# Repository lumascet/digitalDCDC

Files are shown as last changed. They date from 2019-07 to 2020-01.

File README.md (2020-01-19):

# Atmel atmega 328p DCDC controller
Arduino Uno Project for digitally controlling DCDC converter with adc & dac over i2c with dotmatrix display.
Utilizes the cheap B3606 analog DCDC converter circuit.

The onboard 4.096V reference in combination with 2 12bit DACs as well as one 4 Channel 16bit ADC enable accurate voltage and current setpoints. 

The graphical interface also features a graph display, showing voltage and current over time.

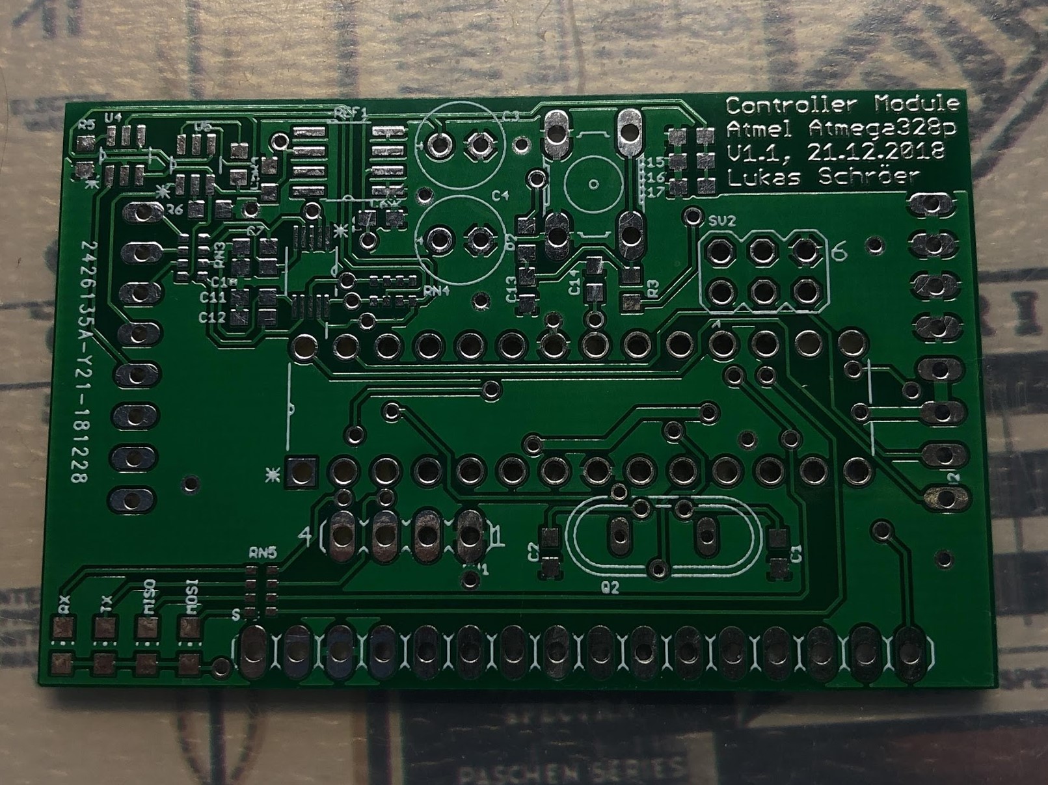
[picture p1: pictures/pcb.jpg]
pcb

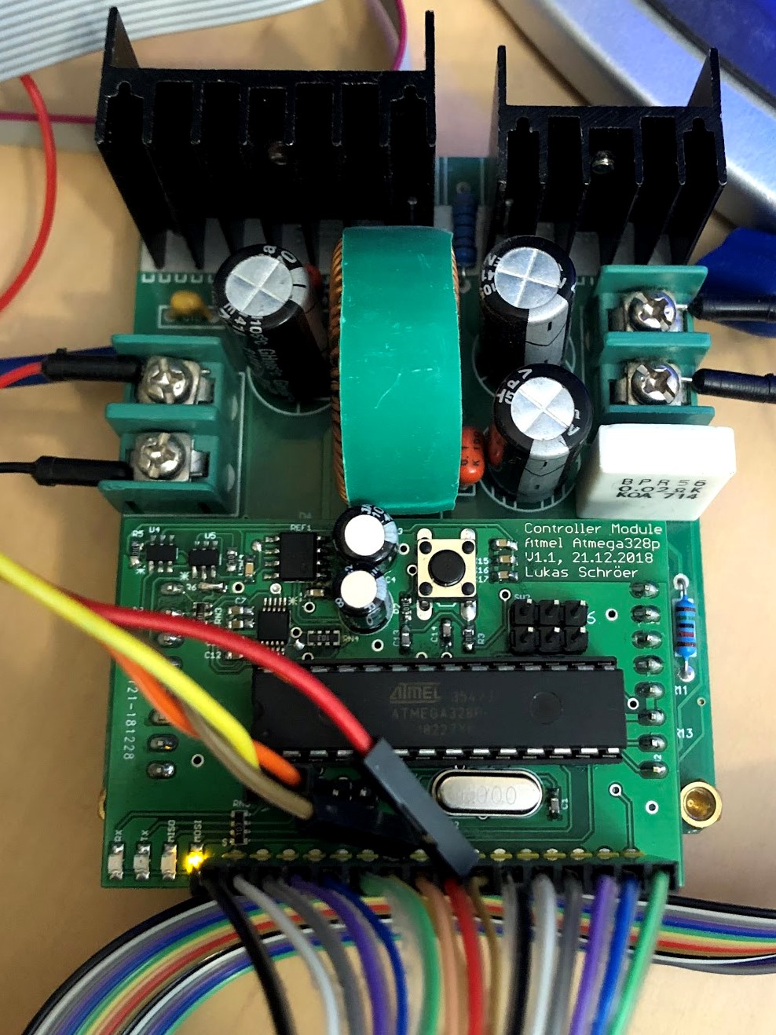
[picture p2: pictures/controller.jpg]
controller

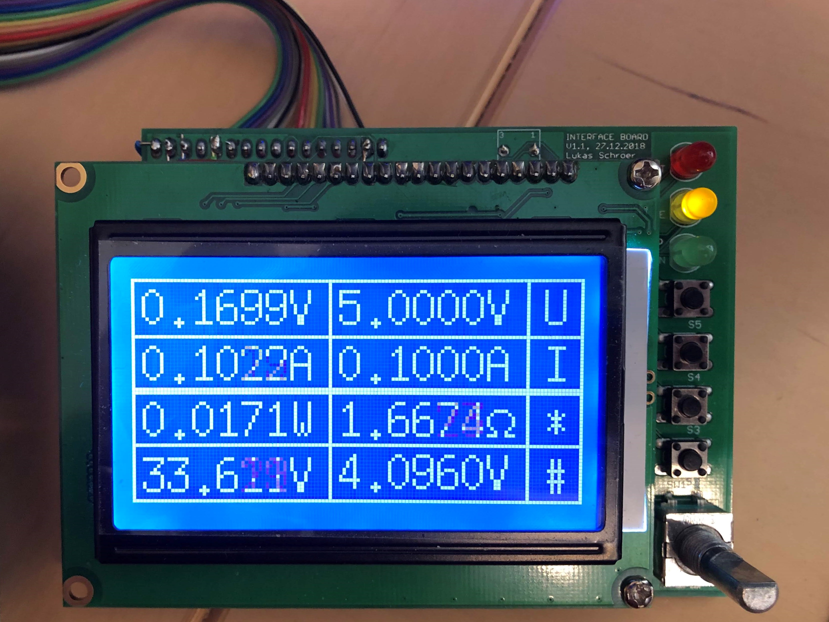
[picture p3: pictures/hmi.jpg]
hmi


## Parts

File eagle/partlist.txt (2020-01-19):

Partlist

Exported from ControllerRC2.brd at 25.02.2019 17:07

EAGLE Version 9.2.2 Copyright (c) 1988-2018 Autodesk, Inc.

Assembly variant: 

Part     Value           Package            Library                                Position (inch)       Orientation

C1       22p             C0603              rcl                                    (2.6 2.0625)          R270
C2       22p             C0603              rcl                                    (2.075 2.0625)        R270
C3       10µ             E2,5-6E            rcl                                    (1.8625 3.05)         R0
C4       10µ             E2,5-6E            rcl                                    (1.8625 2.8125)       R0
C5       1n              C0603              rcl                                    (1.39375 2.96875)     R90
C6       100n            C0603              rcl                                    (1.66875 2.86875)     R0
C7       1µ              C0603              rcl                                    (1.3625 2.8)          R180
C8       330n            C0603              rcl                                    (1.2875 1.890625)     MR90
C9       100n            C0603              rcl                                    (1.2875 2.0125)       MR90
C10      1µ              C0603              rcl                                    (1.3625 2.75)         R180
C11      1µ              C0603              rcl                                    (1.3625 2.675)        R180
C12      1µ              C0603              rcl                                    (1.3625 2.625)        R180
C13      22p             C0603              rcl                                    (2.025 2.6875)        R270
C14      22p             C0603              rcl                                    (2.1875 2.7125)       R90
C15      100n            C0603              rcl                                    (2.425 3.0625)        R180
C16      100n            C0603              rcl                                    (2.425 3)             R180
C17      100n            C0603              rcl                                    (2.425 2.9375)        R180
IC1      MCP602SN        SO08               linear                                 (1.3 2.675)           MR0
IC4      REG1117-3.3     SOT223             burr-brown                             (1.0875 1.95)         MR270
MISO     YELLOW          CHIP-LED0805       led                                    (1.1375 1.85)         R0
MOSI     YELLOW          CHIP-LED0805       led                                    (1.2375 1.85)         R0
Q2       16M             QS                 special                                (2.3375 2.1)          R180
R1       10k             R0603              rcl                                    (1.375 2.475)         MR180
R2       10k             R0603              rcl                                    (2.025 2.8125)        R90
R3       10k             R0603              rcl                                    (2.275 2.6875)        R270
R4       10k             R0603              rcl                                    (1.31875 3.00625)     R270
R5       10k             R0603              rcl                                    (0.9375 3.03125)      R270
R6       0               R0603              rcl                                    (1.25 2.89375)        R180
R7       10k             R0603              rcl                                    (2.1375 2.35)         MR180
R8       33k             R0603              rcl                                    (1.7875 2.3625)       MR270
R9       33k             R0603              rcl                                    (1.9375 2.3625)       MR270
R10      10k             R0603              rcl                                    (2.1375 2.4125)       MR180
R11      6.8k            R0603              rcl                                    (1.25 2.475)          MR180
REF1     ISL21009BFB841Z SOIC127P600X175-8N custom                                 (1.5875 3.0125)       R180
RN3      10k             0603-ARC           resistor-dil                           (1.2125 2.775)        R270
RN4      10k             0603-ARC           resistor-dil                           (1.7 2.6875)          R0
RN5      1k              0603-ARC           resistor-dil                           (1.4 1.975)           R90
RX       YELLOW          CHIP-LED0805       led                                    (0.9375 1.85)         R0
S1                       B3F-10XX           switch-omron                           (2.1875 2.946875)     R90
SV1                      MA04-1             con-lstb                               (1.7375 2.1)          R180
SV2                      MA03-2             con-lstb                               (2.5875 2.725)        R0
SV3                      1X16               pinhead                                (2.1375 1.8375)       R0
TX       YELLOW          CHIP-LED0805       led                                    (1.0375 1.85)         R0
U$1      DCPINHEADER     CDIP16             custom                                 (2.0875 2.5875)       R0
U1       ADS1115IDGST    SOP50P490X110-10N  Texas Instruments_By_element14_Batch_1 (1.5 2.7375)          R270
U2       ATMEGA328P-PU   DIP254P762X457-28  Atmel_By_element14_Batch_1-00          (2.7875 2.55)         R90
U4       MCP4725A0T-E/CH SOT95P270X145-6N   Microchip_By_element14_Batch_1         (1.0375 3.03125)      R90
U5       MCP4725A0T-E/CH SOT95P270X145-6N   Microchip_By_element14_Batch_1         (1.2125 3.00625)      R90

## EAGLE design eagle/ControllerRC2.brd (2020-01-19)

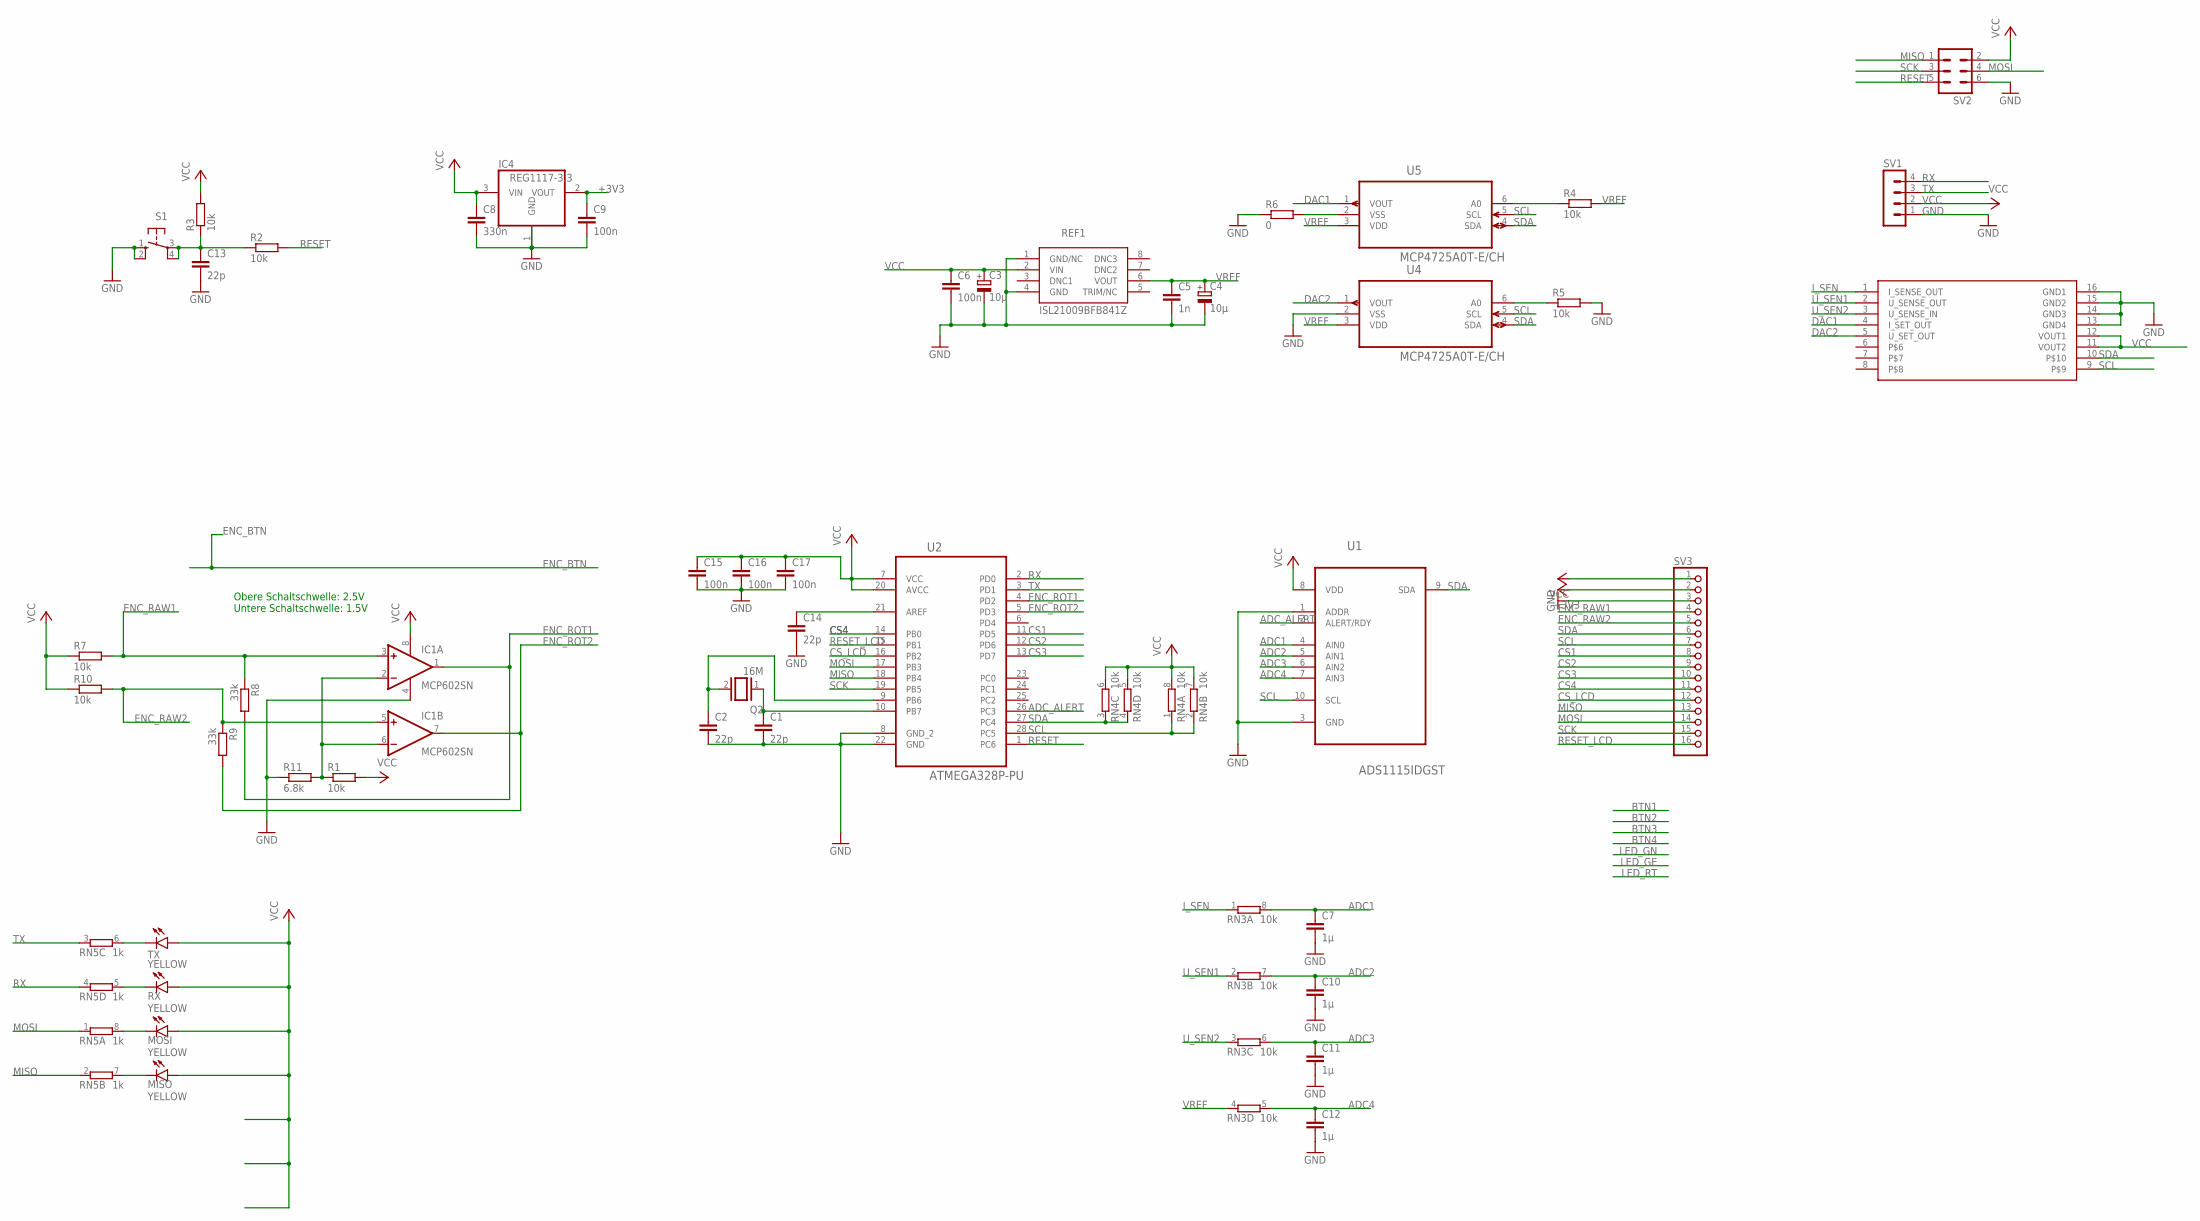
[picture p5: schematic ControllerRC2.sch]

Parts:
C1, C2, C13, C14: 22p; C0603
C3, C4: 10µ; E2,5-6E
C5: 1n; C0603
C6, C9, C15, C16, C17: 100n; C0603
C7, C10, C11, C12: 1µ; C0603
C8: 330n; C0603
IC1: MCP602SN; SO08
IC4: REG1117-3.3; SOT223
MISO: YELLOW; CHIP-LED0805
MOSI: YELLOW; CHIP-LED0805
Q2: 16M; QS
R1, R2, R3, R4, R5, R7, R10: 10k; R0603
R6: 0; R0603
R8, R9: 33k; R0603
R11: 6.8k; R0603
REF1: ISL21009BFB841Z; SOIC127P600X175-8N
RN3, RN4: 10k; 0603-ARC
RN5: 1k; 0603-ARC
RX: YELLOW; CHIP-LED0805
S1: 10-XX; B3F-10XX
SV1: MA04-1
SV2: MA03-2
SV3: PINHD-1X16; 1X16
TX: YELLOW; CHIP-LED0805
U1: ADS1115IDGST; SOP50P490X110-10N
U2: ATMEGA328P-PU; DIP254P762X457-28
U4, U5: MCP4725A0T-E/CH; SOT95P270X145-6N
U$1: DCPINHEADER; CDIP16

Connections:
+3V3: C9.1, IC4.2 (VOUT), SV3.2
ADC1: C7.1, RN3.8 (2), U1.4 (AIN0)
ADC2: C10.1, RN3.7 (2), U1.5 (AIN1)
ADC3: C11.1, RN3.6 (2), U1.6 (AIN2)
ADC4: C12.1, RN3.5 (2), U1.7 (AIN3)
ADC_ALERT: U1.2 (ALERT/RDY), U2.26 (PC3)
CS1: SV3.8, U2.11 (PD5)
CS2: SV3.9, U2.12 (PD6)
CS3: SV3.10, U2.13 (PD7)
CS4: SV3.11, U2.14 (PB0)
CS_LCD: SV3.12, U2.16 (PB2)
DAC1: U5.1 (VOUT), U$1.4 (I_SET_OUT)
DAC2: U4.1 (VOUT), U$1.5 (U_SET_OUT)
ENC_RAW1: IC1.3 (+IN), R7.2, R8.1, SV3.4
ENC_RAW2: IC1.5 (+IN), R9.1, R10.2, SV3.5
ENC_ROT1: IC1.1 (OUT), R8.2, U2.4 (PD2)
ENC_ROT2: IC1.7 (OUT), R9.2, U2.5 (PD3)
GND: C1.2, C2.2, C3.-, C4.-, C5.2, C6.2, C7.2, C8.2, C9.2, C10.2, C11.2, C12.2, C13.2, C14.2, C15.2, C16.2, C17.2, IC1.4 (V-), IC4.1 (GND), R5.2, R6.1, R11.1, REF1.1 (GND/NC), REF1.4 (GND), S1.1 (S), S1.2 (S1), SV1.1, SV2.6, SV3.3, U1.1 (ADDR), U1.3 (GND), U2.8 (GND_2), U2.22 (GND), U4.2 (VSS), U$1.13 (GND4), U$1.14 (GND3), U$1.15 (GND2), U$1.16 (GND1)
I_SEN: RN3.1, U$1.1 (I_SENSE_OUT)
MISO: RN5.2 (1), SV2.1, SV3.13, U2.18 (PB4)
MOSI: RN5.1, SV2.4, SV3.14, U2.17 (PB3)
unnamed: C1.1, Q2.1, U2.10 (PB7)
unnamed: RN5.6 (2), TX.C
unnamed: RN5.5 (2), RX.C
unnamed: MOSI.C, RN5.8 (2)
unnamed: MISO.C, RN5.7 (2)
unnamed: C2.1, Q2.2, U2.9 (PB6)
unnamed: C14.1, U2.21 (AREF)
unnamed: R4.1, U5.6 (A0)
unnamed: R5.1, U4.6 (A0)
unnamed: R6.2, U5.2 (VSS)
unnamed: IC1.2 (-IN), IC1.6 (-IN), R1.1, R11.2
unnamed: C13.1, R2.1, R3.1, S1.3, S1.4 (P1)
RESET: R2.2, SV2.5, U2.1 (PC6)
RESET_LCD: SV3.16, U2.15 (PB1)
RX: RN5.4 (1), SV1.4, U2.2 (PD0)
SCK: SV2.3, SV3.15, U2.19 (PB5)
SCL: RN4.1, RN4.2 (1), SV3.7, U1.10 (SCL), U2.28 (PC5), U4.5 (SCL), U5.5 (SCL), U$1.9
SDA: RN4.3 (1), RN4.4 (1), SV3.6, U1.9 (SDA), U2.27 (PC4), U4.4 (SDA), U5.4 (SDA), U$1.10
TX: RN5.3 (1), SV1.3, U2.3 (PD1)
U_SEN1: RN3.2 (1), U$1.2 (U_SENSE_OUT)
U_SEN2: RN3.3 (1), U$1.3 (U_SENSE_IN)
VCC: C3.+, C6.1, C8.1, C15.1, C16.1, C17.1, IC1.8 (V+), IC4.3 (VIN), MISO.A, MOSI.A, R1.2, R3.2, R7.1, R10.1, REF1.2 (VIN), RN4.5 (2), RN4.6 (2), RN4.7 (2), RN4.8 (2), RX.A, SV1.2, SV2.2, SV3.1, TX.A, U1.8 (VDD), U2.7 (VCC), U2.20 (AVCC), U$1.11 (VOUT2), U$1.12 (VOUT1)
VREF: C4.+, C5.1, R4.2, REF1.6 (VOUT), RN3.4 (1), U4.3 (VDD), U5.3 (VDD)

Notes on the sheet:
Obere Schaltschwelle: 2.5V Untere Schaltschwelle: 1.5V

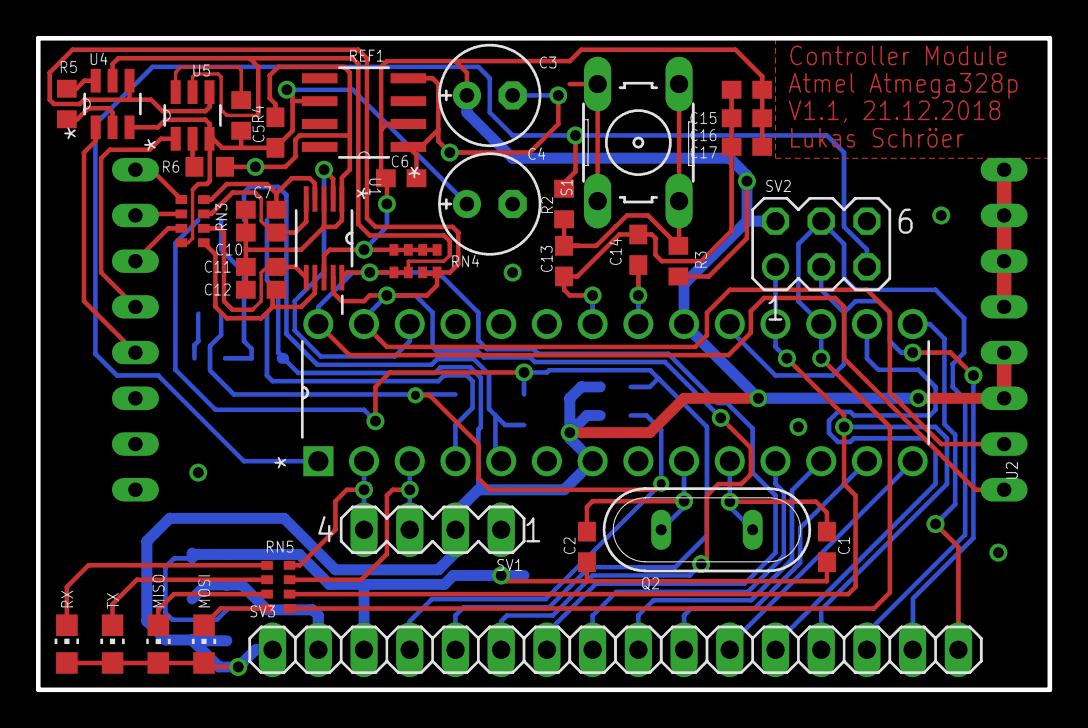
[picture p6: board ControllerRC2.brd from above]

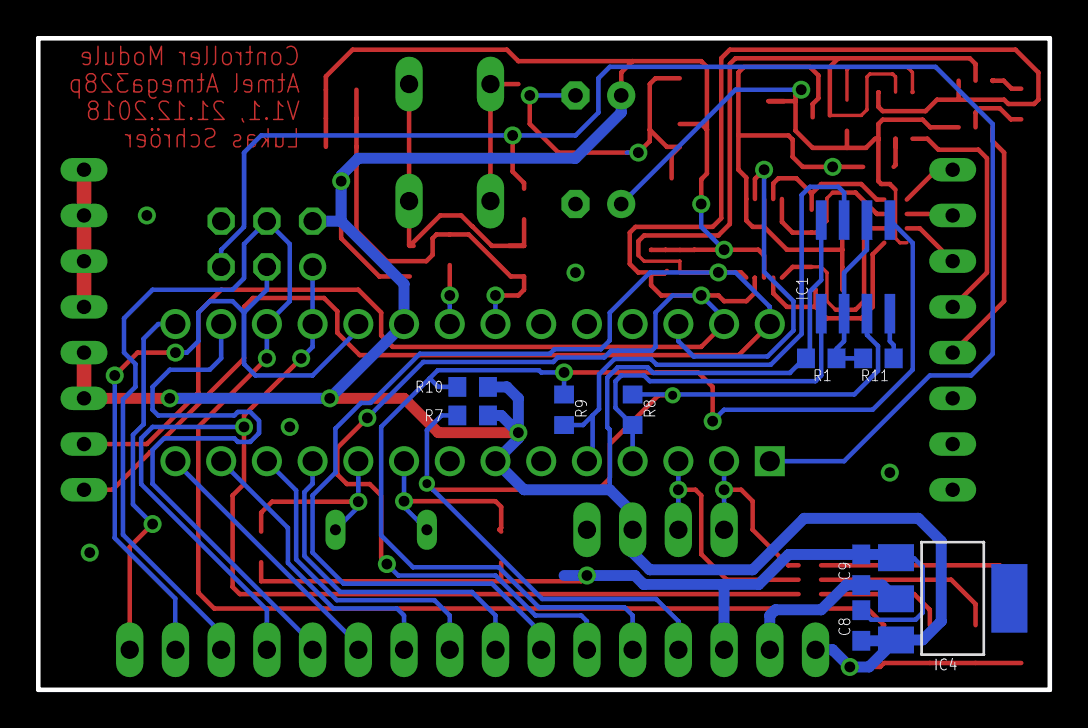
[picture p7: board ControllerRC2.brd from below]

Board: 2 copper layers, 56.2 x 36.2 mm, 48 parts (10 on the bottom side), 44 nets.

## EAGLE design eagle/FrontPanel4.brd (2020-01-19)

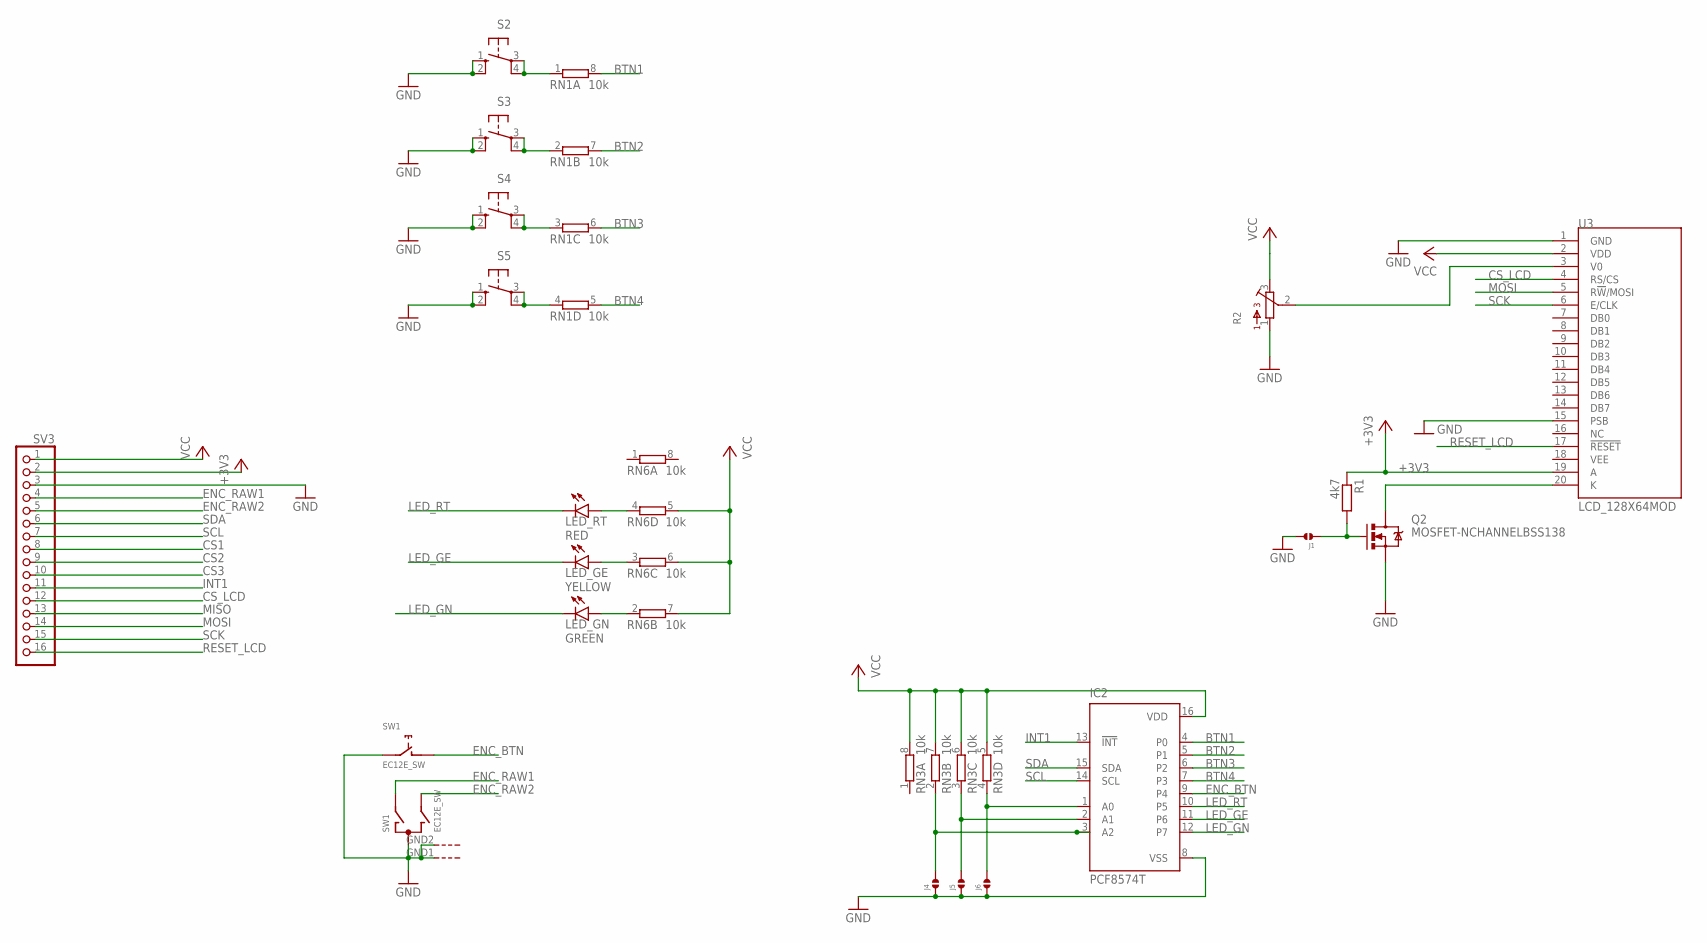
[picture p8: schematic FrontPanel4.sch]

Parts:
IC2: PCF8574T; SO16W
J1, J4, J5, J6: SOLDERJUMPER.2.MED; 2.MED
LED_GE: YELLOW; LED5MM
LED_GN: GREEN; LED5MM
LED_RT: RED; LED5MM
Q2: MOSFET-NCHANNELBSS138; SOT23
R1: 4k7; R1206
R2: 3362P
RN1, RN3, RN6: 10k; 0603-ARC
S2, S3, S4, S5: 10-XX; B3F-10XX
SV3: PINHD-1X16; 1X16
SW1: EC12E_SW; ALPS_EC12E_SW
U3: LCD_128X64MOD; LCD_128X64_MOD

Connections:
+3V3: R1.1, SV3.2, U3.19 (A)
BTN1: IC2.4 (P0), RN1.8 (2)
BTN2: IC2.5 (P1), RN1.7 (2)
BTN3: IC2.6 (P2), RN1.6 (2)
BTN4: IC2.7 (P3), RN1.5 (2)
CS1: SV3.8
CS2: SV3.9
CS3: SV3.10
CS_LCD: SV3.12, U3.4 (RS/CS)
ENC_BTN: IC2.9 (P4), SW1.D (1)
ENC_RAW1: SV3.4, SW1.A
ENC_RAW2: SV3.5, SW1.B
GND: IC2.8 (VSS), J1.2, J4.1, J5.1, J6.1, Q2.2 (S), R2.1, S2.1 (S), S2.2 (S1), S3.1 (S), S3.2 (S1), S4.1 (S), S4.2 (S1), S5.1 (S), S5.2 (S1), SV3.3, SW1.C, SW1.E (2), SW1.GND1 (G), SW1.GND2 (G), U3.1 (GND), U3.15 (PSB)
INT1: IC2.13 (!INT), SV3.11
LED_GE: IC2.11 (P6), LED_GE.K (C)
LED_GN: IC2.12 (P7), LED_GN.K (C)
LED_RT: IC2.10 (P5), LED_RT.K (C)
MISO: SV3.13
MOSI: SV3.14, U3.5 (R!W!/MOSI)
unnamed: R2.2, U3.3 (V0)
unnamed: RN1.1, S2.3, S2.4 (P1)
unnamed: RN1.2 (1), S3.3, S3.4 (P1)
unnamed: RN1.3 (1), S4.3, S4.4 (P1)
unnamed: RN1.4 (1), S5.3, S5.4 (P1)
unnamed: IC2.1 (A0), J6.2, RN3.4 (1)
unnamed: IC2.2 (A1), J5.2, RN3.3 (1)
unnamed: IC2.3 (A2), J4.2, RN3.2 (1)
unnamed: LED_RT.A, RN6.4 (1)
unnamed: LED_GE.A, RN6.3 (1)
unnamed: LED_GN.A, RN6.2 (1)
unnamed: Q2.3 (D), U3.20 (K)
unnamed: J1.1, Q2.1 (G), R1.2
RESET_LCD: SV3.16, U3.17 (!RESET!)
SCK: SV3.15, U3.6 (E/CLK)
SCL: IC2.14 (SCL), SV3.7
SDA: IC2.15 (SDA), SV3.6
VCC: IC2.16 (VDD), RN3.5 (2), RN3.6 (2), RN3.7 (2), RN3.8 (2), RN6.5 (2), RN6.6 (2), RN6.7 (2), SV3.1, U3.2 (VDD)

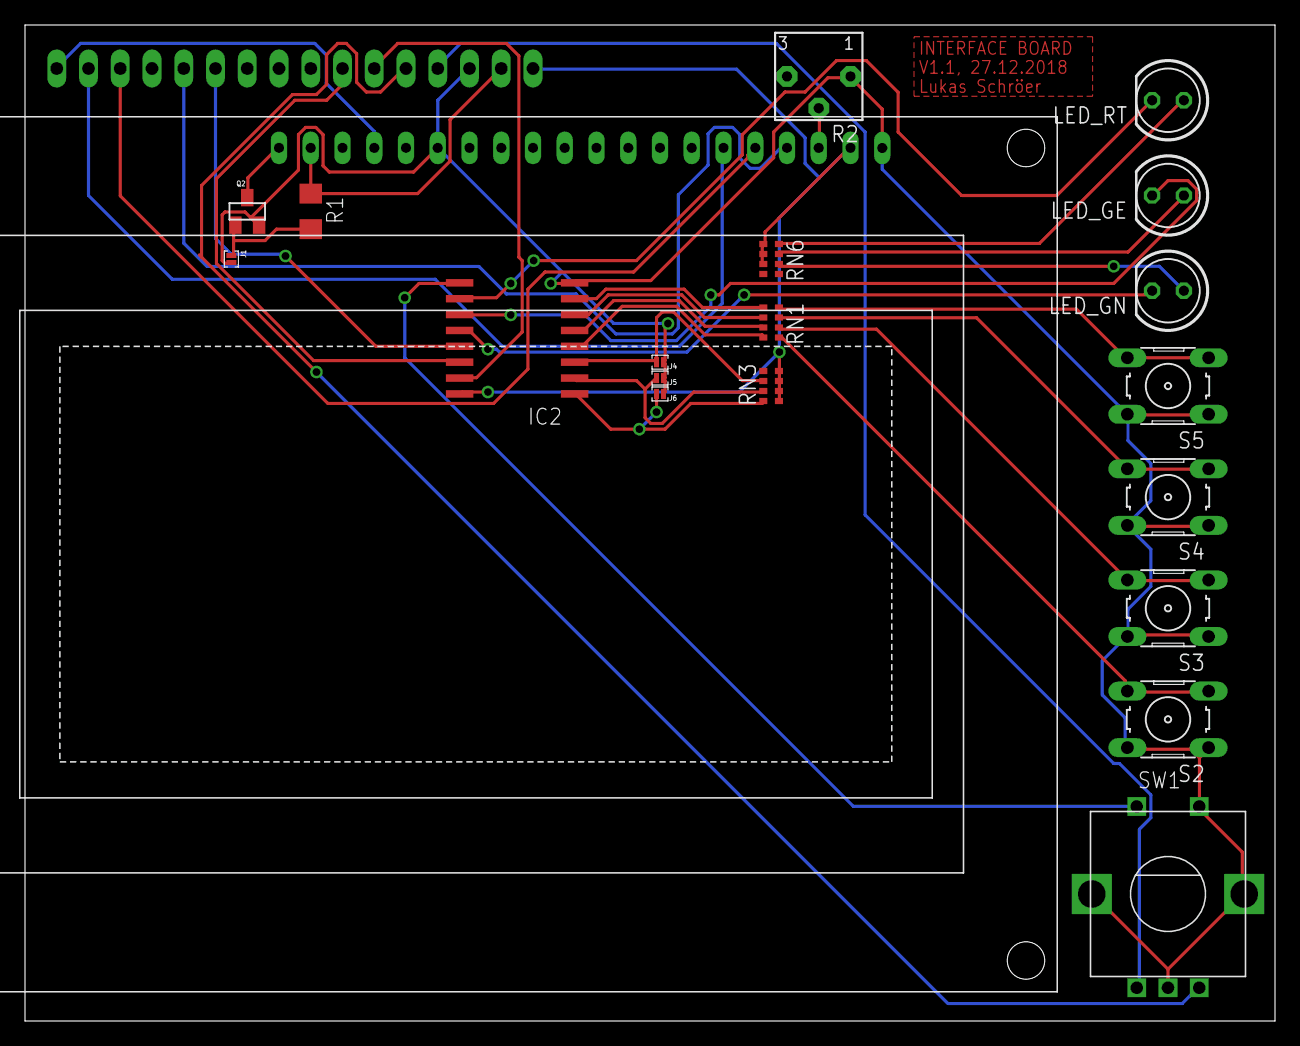
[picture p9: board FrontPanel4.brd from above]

Board: 2 copper layers, 100.0 x 79.7 mm, 21 parts (1 on the bottom side), 33 nets.

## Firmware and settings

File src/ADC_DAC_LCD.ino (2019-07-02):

#define OFF         "\033[0m"
#define BOLD        "\033[1m"
#define LOWINTENS   "\033[2m"
#define UNDERLINE   "\033[4m"
#define BLINK       "\033[5m"
#define REVERSE     "\033[7m"
#define RESCURS     "\033[0;0H"   // Esc[Line;ColumnH
#define CLS         "\033[2J"     // Esc[2J Clear entire screen

#define STRING_SIZE 9

#include <Wire.h>
#include <SPI.h>
#include <EEPROM.h>

#include <Adafruit_ADS1015.h>
#include <Adafruit_MCP4725.h>
#include <IoAbstraction.h>
#include <IoAbstractionWire.h>
#include <Encoder.h>
#include <U8g2lib.h>

#define P(X) (Serial.println(X))

Adafruit_ADS1115 ads;  /* Use this for the 16-bit version */
Adafruit_MCP4725 dacu;
Adafruit_MCP4725 daci;
U8G2_ST7920_128X64_1_HW_SPI u8g2(U8G2_R2, /* CS=*/ 10, /* reset=*/ 9);
IoAbstractionRef ioExpander = ioFrom8574(0x27);
Encoder enc(3, 2);

const float cal_u_low  = 2; //V
const float cal_u_high = 30; //V
const float cal_i_low  = 0.2; //A
const float cal_i_high = 2; //A

const float imax = 6;
const float umax = 36;
const float constrainVal[] = {imax, umax};
const uint16_t int16max = 0xFFFF;


uint16_t ringbuf[128][2];
uint8_t idx = 0;

byte menu_page = 0;
int edit_val = -1;
int edit_digit = 0;

float cal_v_ref;
float calibration_data[5][2];
/*
 * 1- DAC V
 * 2- DAC I
 * 3- ADC U
 * 4- ADC I
 * 5- ADC UEXT
 */
float set_data[2] {0.1, 5};
bool output_state = 0;
bool output_cc = 0;

enum dacport {
        dac_i = 0,
        dac_u = 1,
};

enum buttons {
        S2,
        S3,
        S4,
        S5,
        S1
};

enum bufItems {
        CURRENT,
        VOLTAGE,
        VOLTAGE_IN,
        VOLTAGE_REF,
        POWER,
        RESISTANCE,
        SET_CURRENT,
        SET_VOLTAGE
};

const uint8_t cOhm[] = {
        B00000011, B11000000,
        B00000100, B00100000,
        B00001000, B00010000,
        B00001000, B00010000,
        B00001000, B00010000,
        B00000100, B00100000,
        B00000010, B01000000,
        B00001110, B01110000
};



void setup(void){
        u8g2.begin();
        delay(500);
        setupI2C();
        calibrate();

}

void loop(){

        float f_adc[6];

        for(int i=0; i<4; i++) {
                f_adc[i] = adcCalRead(i);
        }
        output_cc = (f_adc[1] < set_data[1]- 0.1 ) ? 1 : 0; //check if voltage is out for cc

        saveBuffer(f_adc);
        buttonPoll();
        systemTask(f_adc);
        serialMenu();
}

long encPoll(){
        static long encOldPosition = 0;
        long encNewPosition, diff;
        encNewPosition = enc.read()/4;
        diff = encNewPosition-encOldPosition;
        encOldPosition = encNewPosition;
        return diff;
}

void systemTask(float f_adc[]){
        static unsigned long starttime = 0;
        const unsigned int timediff = 200;//ms
        if(edit_val!=-1) {
                P(constrainVal[edit_val]);
                //P(set_data[edit_val] + encPoll() * pow(10,edit_digit));
                float f = set_data[edit_val] + encPoll() * pow(10,edit_digit);
                set_data[edit_val] = constrain(f, 0, constrainVal[edit_val]);
        }
        if((millis() - starttime)>timediff) {
                char buf[8][STRING_SIZE]; //GLOBAL VAR Reduces Error probability
                f_adc[4] = f_adc[1] * f_adc[0]; //POWER
                f_adc[5] = f_adc[1] / f_adc[0]; //RESISTANCE
                for(int i=0; i<6; i++) {
                        generateString(buf[i], i, f_adc[i]);
                }
                for(int i=6; i<8; i++) {
                        generateString(buf[i], i, set_data[i-6]); //
                }
                lcdRefresh(buf);
                starttime = millis();
        }
}

void saveBuffer(float f_adc[]){
        idx++;
        if(idx==127)
                idx=0;

        ringbuf[idx][0] = round(constrain(f_adc[0],0,imax) * int16max / imax);
        ringbuf[idx][1] = round(constrain(f_adc[1],0,umax) * int16max / umax);
        //P(idx);
        //P(ringbuf[idx][0]);
}

void buttonPoll(){
        static int lastpress = -1;
        int activepress = -1;

        ioDeviceDigitalWrite(ioExpander, 5, output_state);
        if(output_state) {
                ioDeviceDigitalWrite(ioExpander, 6, !output_cc);
                ioDeviceDigitalWrite(ioExpander, 7, output_cc);
        }
        else{
                ioDeviceDigitalWrite(ioExpander, 6, 1);
                ioDeviceDigitalWrite(ioExpander, 7, 1);
        }
        ioDeviceSync(ioExpander);
        for(int i=0; i<5; i++) {
                if(!ioDeviceDigitalRead(ioExpander, i))
                        activepress = i;
        }
        if(activepress == S2 && lastpress != S2) {
                P("S2");
                output_state = !output_state;
                lastpress = S2;
                if(output_state) {
                        setOutput(dac_u,set_data[dac_u],true);
                        setOutput(dac_i,set_data[dac_i],true);
                }
                else{
                        setOutput(dac_u,-1,true);
                        setOutput(dac_i,-1,true);
                }
        }
        else if(activepress == S3 && lastpress != S3) {

                lastpress = S3;
                if(menu_page == 0)
                        menu_page = 1;
                else
                        menu_page = 0;
                P("S3");
        }
        else if(activepress == S4 && lastpress != S4) {
                lastpress = S4;
                edit_val = (edit_val!=CURRENT) ? CURRENT :  -1;
                edit_digit = 0;
                P("S4");
        }
        else if(activepress == S5 && lastpress != S5) {
                lastpress = S5;
                edit_val = (edit_val!=VOLTAGE) ? VOLTAGE :  -1;
                edit_digit = 0;
                P("S5");
        }
        else if(activepress == S1 && lastpress != S1) {
                lastpress = S1;
                switch(edit_val) {
                case VOLTAGE:
                        edit_digit--;
                        if(edit_digit==-4)
                                edit_digit=1;
                        break;
                case CURRENT:
                        edit_digit--;
                        if(edit_digit==-5)
                                edit_digit=0;
                        break;

                }
                P("S1");

        }
        else if(activepress == -1) {
                lastpress = -1;
        }
}

void lcdRefresh(char buf[][STRING_SIZE]){
        uint16_t maxval[2] = {1, 1};
        char tmp[2][5];
        //Serial.println(buf[1]);
        //Serial.println(buf[0]);
        u8g2.firstPage();
        switch(menu_page) {
        case 1:
                for(int i=0; i<127; i++) {
                        if(ringbuf[i][0] > maxval[0])
                                maxval[0] = constrain(ringbuf[i][0],1,int16max);
                        if(ringbuf[i][1] > maxval[1])
                                maxval[1] = constrain(ringbuf[i][1],1,int16max);
                }
                floatToVariableString(tmp[0], (float)maxval[0]*imax/int16max, 4, 0, imax);
                floatToVariableString(tmp[1], (float)maxval[1]*umax/int16max, 4, 0, umax);
                do {
                        //u8g2.drawFrame(0, 0, 128, 64);
                        u8g2.setFont(u8g2_font_t0_12_tr);
                        u8g2.drawHLine(0,31,128);
                        u8g2.drawHLine(0,32,128);
                        u8g2.drawStr(3,13, "U");
                        u8g2.drawStr(100,13, tmp[1]);
                        u8g2.drawStr(3,32+13, "I");
                        u8g2.drawStr(100,32+13, tmp[0]);
                        for(int i=0; i<126; i++) {
                                if(i==idx) continue;
                                long l[4];
                                l[0] = 30-constrain(30*(long)ringbuf[i][1]/maxval[1],0,int16max);
                                l[1] = 30-constrain(30*(long)ringbuf[i+1][1]/maxval[1],0,int16max);
                                l[2] = 63-constrain(30*(long)ringbuf[i][0]/maxval[0],0,int16max);
                                l[3] = 63-constrain(30*(long)ringbuf[i+1][0]/maxval[0],0,int16max);
                                u8g2.drawLine(i, l[0], i+1, l[1]);
                                u8g2.drawLine(i, l[2], i+1, l[3]);
                                //u8g2.drawPixel(i, 30-((float)ringbuf[i][1]/(float)maxval[1]*30));
                                //u8g2.drawPixel(i, 63-((float)ringbuf[i][0]/(float)maxval[0]*30));
                        }
                } while ( u8g2.nextPage() );
                break;
        default:
                char cursor[] = {113,'\n'};
                static bool blinkState = 0;
                blinkState = !blinkState;
                do {
                        u8g2.setFont(u8g2_font_7x14_tr);
                        u8g2.drawStr(3,13, buf[VOLTAGE]);
                        u8g2.drawStr(3,13+16, buf[CURRENT]);
                        u8g2.drawStr(3,13+32, buf[POWER]);
                        u8g2.drawStr(3,13+48, buf[VOLTAGE_IN]);
                        u8g2.drawStr(3+(128-16)/2,13+48, buf[VOLTAGE_REF]);
                        //u8g2.drawStr(110,60, cursor);
                        u8g2.drawStr(3+(128-16)/2,13, buf[SET_VOLTAGE]);
                        u8g2.drawStr(3+(128-16)/2,13+16, buf[SET_CURRENT]);
                        u8g2.drawBitmap( 97, 37, 2, 8, cOhm);
                        u8g2.drawStr(3+(128-16)/2,13+32, buf[RESISTANCE]);
                        u8g2.drawStr(117,13, "U");
                        u8g2.drawStr(117,13+16, "I");
                        u8g2.drawFrame(0, 0, 128, 64);
                        u8g2.drawFrame(0, 16, 128, 16);
                        u8g2.drawFrame(0, 32, 128, 16);
                        u8g2.drawVLine(128-16, 0, 64);
                        u8g2.drawVLine((128-16)/2, 0, 64);
                        switch(edit_val) {
                        case VOLTAGE:
                                if(blinkState)
                                        u8g2.drawStr(66,13, "_");
                                u8g2.drawStr(117,13+32, "<");
                                u8g2.drawStr(117,13+48, ">");
                                break;
                        case CURRENT:
                                if(blinkState)
                                        u8g2.drawStr(59,13+16, "_");
                                u8g2.drawStr(117,13+32, "<");
                                u8g2.drawStr(117,13+48, ">");
                                break;
                        default:
                                u8g2.drawStr(117,13+32, "G");
                                u8g2.drawStr(117,13+48, "O");
                                break;
                        }
                } while ( u8g2.nextPage() );
                break;
        }
}

void serialMenu(){
        char dummy;
        static int a = 0;
        static bool listen = 0;
        if ((Serial.available() > 0) && a != 0) {
                float f;
                switch(a) {
                case 1:
                        a = Serial.parseInt();
                        Serial.println(a);
                        if(a) {
                                setOutput(dac_u,set_data[dac_u],true);
                                setOutput(dac_i,set_data[dac_i],true);
                        }
                        else{
                                setOutput(dac_u,-1,true);
                                setOutput(dac_i,-1,true);
                        }
                        break;
                case 2:
                        f = Serial.parseFloat();
                        Serial.println(f);
                        setOutput(dac_u,f,false);
                        break;
                case 3:
                        f = Serial.parseFloat();
                        Serial.println(f);
                        setOutput(dac_i,f,false);
                        break;
                }
                a=0;
                while(Serial.available()) dummy=Serial.read();
        }
        //Serial.println(Serial.available());
        if ((Serial.available() > 0) && a==0) {
                a = Serial.parseInt();
                while(Serial.available()) dummy=Serial.read();
                switch(a) {
                case 1:
                        Serial.print("State["+ (String)output_state+ "]: ");
                        break;
                case 2:
                        Serial.print("Vset["+ (String)set_data[dac_u]+ "]: ");
                        break;
                case 3:
                        Serial.print("Iset["+ (String)set_data[dac_i]+ "]: ");
                        break;
                }
        }
}

void setupI2C(){
        Serial.begin(115200);
        Wire.begin();

        ioDevicePinMode(ioExpander, 0, INPUT);
        ioDevicePinMode(ioExpander, 1, INPUT);
        ioDevicePinMode(ioExpander, 2, INPUT);
        ioDevicePinMode(ioExpander, 3, INPUT);
        ioDevicePinMode(ioExpander, 4, INPUT);
        ioDevicePinMode(ioExpander, 5, OUTPUT);
        ioDevicePinMode(ioExpander, 6, OUTPUT);
        ioDevicePinMode(ioExpander, 7, OUTPUT);

        ioDeviceDigitalWrite(ioExpander, 5, 0);
        ioDeviceDigitalWrite(ioExpander, 6, 1);
        ioDeviceDigitalWrite(ioExpander, 7, 1);

        ioDeviceSync(ioExpander);

        //                                                                ADS1015  ADS1115
        //                                                                -------  -------
        //ads.setGain(GAIN_TWOTHIRDS);  // 2/3x gain +/- 6.144V  1 bit = 3mV      0.1875mV (default)
        ads.setGain(GAIN_ONE);  // 1x gain   +/- 4.096V  1 bit = 2mV      0.125mV
        // ads.setGain(GAIN_TWO);        // 2x gain   +/- 2.048V  1 bit = 1mV      0.0625mV
        // ads.setGain(GAIN_FOUR);       // 4x gain   +/- 1.024V  1 bit = 0.5mV    0.03125mV
        // ads.setGain(GAIN_EIGHT);      // 8x gain   +/- 0.512V  1 bit = 0.25mV   0.015625mV
        // ads.setGain(GAIN_SIXTEEN);    // 16x gain  +/- 0.256V  1 bit = 0.125mV  0.0078125mV
        //Serial.print(CLS);
        ads.begin();
        dacu.begin(0x62);
        daci.begin(0x63);

        setOutput(dac_u,-1,true);
        setOutput(dac_i,-1,true);

        delay(100);
}

float adcCalRead(byte channel){
        unsigned int i_adc;
        float f_adc, f_adc2;
        switch(channel) {
        default:
                i_adc = ads.readADC_SingleEnded(channel);
                f_adc = calibration_data[channel+2][0] * (float)i_adc * 0.000125 * cal_v_ref + calibration_data[channel+2][1];
                break;
        case 3:
                i_adc = ads.readADC_SingleEnded(channel);
                f_adc = ((float)i_adc) * 0.000125 * cal_v_ref;
                break;
        }
        if(f_adc<0) f_adc=0;
        return f_adc;
}

void generateString(char* buf, byte channel, float data){
        unsigned char suffix[] = {'A','V', 'V', 'V', 'W', '\0', 'A', 'V'};
        char tmp[STRING_SIZE];
        //Serial.println(buf);
        buf[0]='\0';

        switch(channel) {
        case SET_CURRENT:
                dtostrf(data,6,4,tmp);
                break;
        case SET_VOLTAGE:
                dtostrf(data,6,3,tmp);
                if(data<10)
                        tmp[0]='0';
                break;
        case POWER:
                floatToVariableString(tmp, data, 6, 0, 999);
                break;
        case RESISTANCE:
                floatToVariableString(tmp, data, 6, 0, 999999);
                break;
        default:
                floatToVariableString(tmp, data, 6, 0, 99);
                break;
        }
        strcat(buf, tmp);
        int strl = strlen(buf);
        buf[strl]=suffix[channel];
        buf[strl+1]='\0';
        //Serial.println(buf);
}

void floatToVariableString(char * str, float f, int size, int min, long max){
        f = constrain(f, min, max);
        int dec = constrain((int)log10(f),0,size);
        if(dec > (size-1))
                dtostrf(f,size,size-dec,str);
        else
                dtostrf(f,size,constrain(size-dec-2,0,size),str);
        /*
           if(f<10)
           dtostrf(f,size,4,str);
           else if(f<100)
           dtostrf(f,size,3,str);
           else if(f<1000)
           dtostrf(f,size,2,str);
           else if(f<10000)
           dtostrf(f,size,1,str);
           else
           dtostrf(f,size,0,str);
           //*/
}

void setOutput(byte prop, float value, bool override){
        unsigned int temp;
        switch(prop) {
        case dac_u:
                if(value<0) {
                        output_state = 0;
                        temp = 0;
                }
                else{
                        output_state = 1;
                        temp = calibration_data[0][0]*value + calibration_data[0][1];
                        set_data[1]=value;
                }
                if(output_state == 0 && !override) return;
                dacu.setVoltage(temp, false);
                break;

        case dac_i:
                if(value<0)
                        temp = 0;
                else{
                        temp = calibration_data[1][0]*value + calibration_data[1][1];
                        set_data[0]=value;
                }
                if(output_state == 0 && !override) return;
                daci.setVoltage(temp, false);
                break;

        }
}
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
